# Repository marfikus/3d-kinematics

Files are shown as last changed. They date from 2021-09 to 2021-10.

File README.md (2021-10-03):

# 3d-kinematics

Прошивка для самодельной 3х-осевой кинематики, собранной из имеющегося в наличии хлама. Экспериментальный вариант. Никаких серьёзных подшипников (что конечно сказывается на точности). По оси Z(вертикаль) зубчатые передачи (лоток CD/DVD привода), по осям X,Y фрикционные передачи. Тестил пока только с карандашом, рисуя разные фигуры. Кстати, неплохое учебное пособие для изучения геометрии, тригонометрии, механики, ну и конечно программирования =).

Два режима: работа и калибровка. В режиме калибровки можно отдельно двигать каждую ось и задавать ноль. В рабочем режиме выполняется движение по массиву точек. Можно остановить работу, увести оси на ноль, поднять/опустить голову с карандашом.

В зависимости от настроек, что задаются константами в начале файла прошивки, можно активировать режим движения к каждой точке по нажатию кнопки. Также можно активировать коррекцию погрешности механики (внесение поправки в координаты). Есть ещё разные настройки, которые я постарался снабдить комментариями.

Компоненты:  
Мозги: Arduino UNO  
Шаговые движки: 28BYJ-48 на 5V с драйверами ULN2003. По одному движку на оси X, Y и два на ось Z (включены параллельно).  
Ещё 3 кнопки и два тумблера. Один двухпозиционный для переключения режимов работы, другой трёхпозиционный для переключения осей в режиме калибровки. Ну и несколько резисторов, провода и достаточное желание всё это собрать воедино.

Электрическая схема:
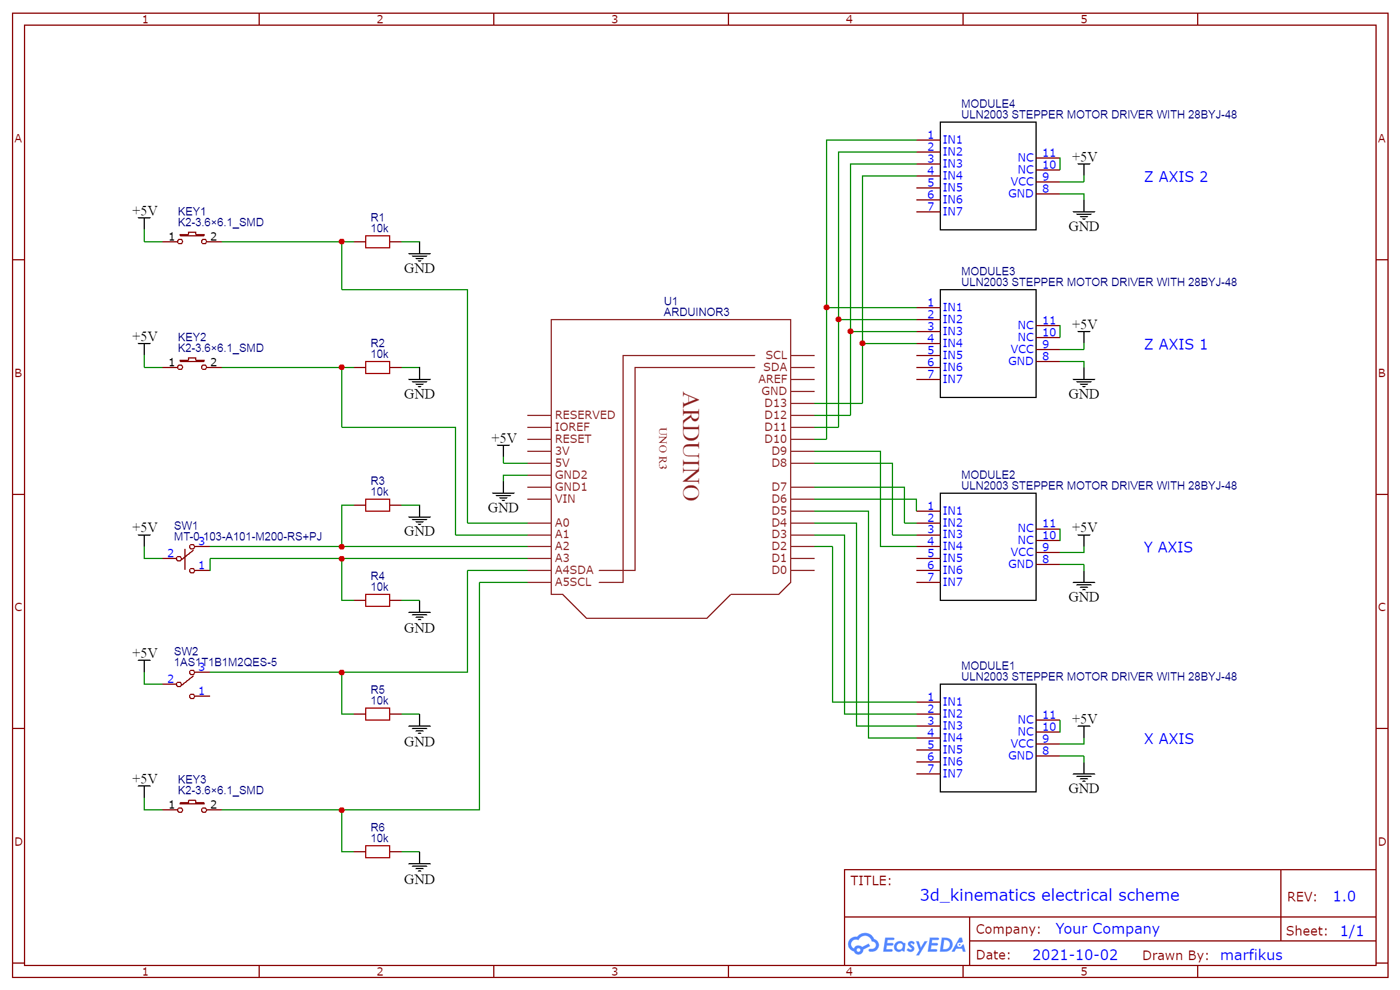
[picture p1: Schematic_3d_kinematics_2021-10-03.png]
Schematic_3d_kinematics_2021-10-03


Статья про то, как всё это создавалось:  
[ВКонтакте](https://vk.com/@marfikus_notes-simple-diy-3d-kinematics)  
[LiveJournal](https://marfikus.livejournal.com/19188.html)

[Краткий видео-обзор и демонстрация работы](https://youtu.be/FhWhIIZW5xA)

В каталоге [3d_models](https://github.com/marfikus/3d-kinematics/tree/master/3d_models) находятся 3d-модели деталей и сборок. Собственно, сначала смоделировал основные узлы (увлекательное занятие), потом начал делать. В реальности всё выглядит практически также.  
Вот модель общей сборки на данный момент (ещё не завершена):
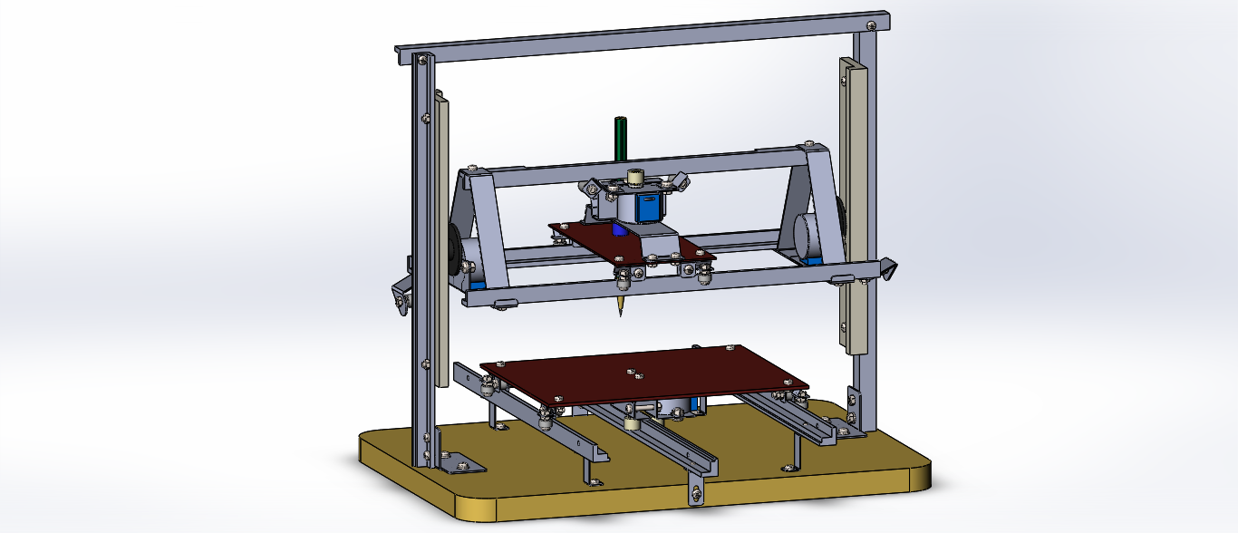
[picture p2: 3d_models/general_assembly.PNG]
general_assembly


Моделировал в Solid Works 2016. Для просмотра можно установить универсальный вьювер eDrawings. Вот [ссылка на его загрузку](https://www.edrawingsviewer.com/download-edrawings) или можно поискать по запросу "solidworks viewer".

Заметил, что включенный Serial мешает рисовать окружности с большим количеством точек. В какой-то момент сбивается с координат и просто ведёт линию по одной из осей. Даже если нет ни одного принта. Если в массиве, например, 60 точек, то отрабатывает нормально, а с 90 уже сбивается.  
По идее надо бы вообще не создавать массив, а отдавать конкретную точку прямо в процессе работы. Так будет гораздо экономичнее по памяти и этот баг наверное устранится. Возможно в будущем так и сделаю.  
При выключенном Serial всё нормально.

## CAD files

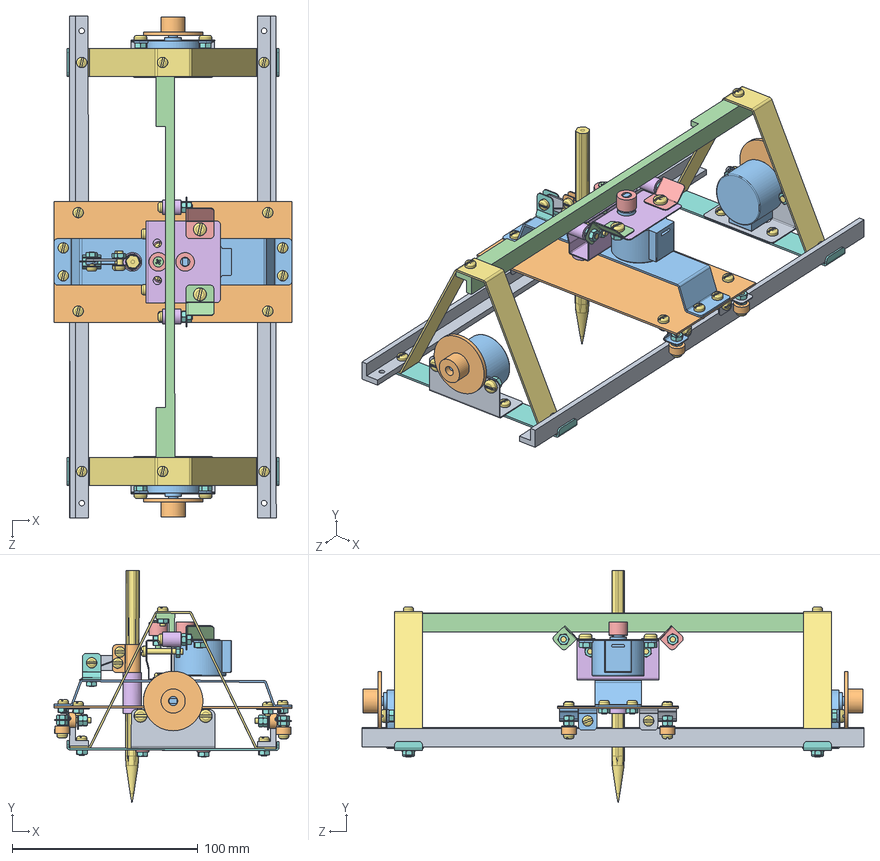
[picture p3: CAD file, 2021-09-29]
3d_models/z_axis_assembly_version_3_final.SLDASM
128.0 x 125.0 x 270.0 mm
corner_rail_2 x 2
table_2
stepper x 3
corner_rail_3
rubberized_roller x 2
table_2_stepper_holder
z_axis_rails_holder_1_1 x 2
z_axis_rails_holder_1_2 x 2
z_axis_stepper_holder x 2
gear_imitation x 2
table_2_stepper_support_2
table_2_stepper_rail_support_left
table_2_stepper_rail_support_right
long_roller x 2
pan slot head_am x 42
hex nut style 1_am x 54
table_support_1 x 2
short_roller x 8
table_support_2 x 2
flat head screw_am
flat washer narrow_am x 6
pencil_tube
pencil
pencil_bracing_1_1
pencil_bracing_1_2
pencil_bracing_1_3
pencil_bracing_spring

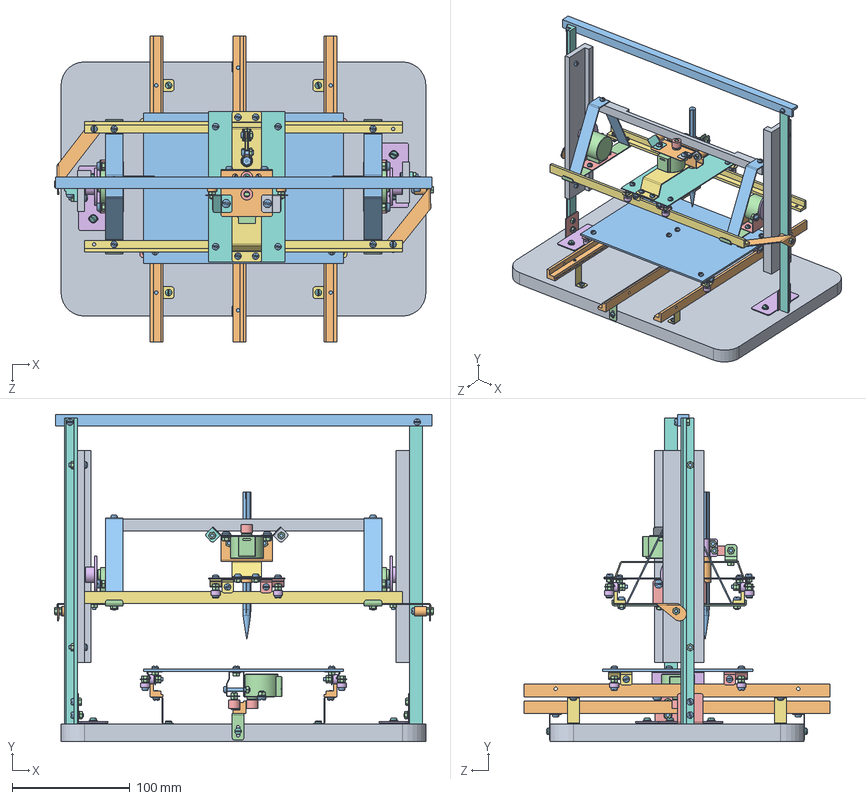
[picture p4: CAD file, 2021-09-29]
3d_models/general_assembly.SLDASM
322.0 x 278.0 x 260.0 mm
base
corner_rail_1 x 3
table_1
stepper x 4
rubberized_roller x 4
table_1_stepper_holder
corner_rail_2 x 2
table_2
corner_rail_3
table_2_stepper_holder
z_axis_rails_holder_1_1 x 2
z_axis_rails_holder_1_2 x 2
z_axis_stepper_holder x 2
gear_imitation x 2
table_2_stepper_support_2
table_2_stepper_rail_support_left
table_2_stepper_rail_support_right
long_roller x 4
pan slot head_am x 80
hex nut style 1_am x 98
table_support_1 x 4
short_roller x 16
table_support_2 x 4
flat head screw_am x 2
flat washer narrow_am x 14
pencil_tube
pencil
pencil_bracing_1_1
pencil_bracing_1_2
pencil_bracing_1_3
pencil_bracing_spring
z_axis_rack x 2
toothed_rail_imitation x 2
z_axis_side_support x 2
z_axis_upper_corner
table_1_stepper_rail_support x 2
z_axis_rack_bracing_1_1 x 2
z_axis_rack_bracing_1_2 x 2
table_1_rail_support x 4
pan head tapping screw_am x 10

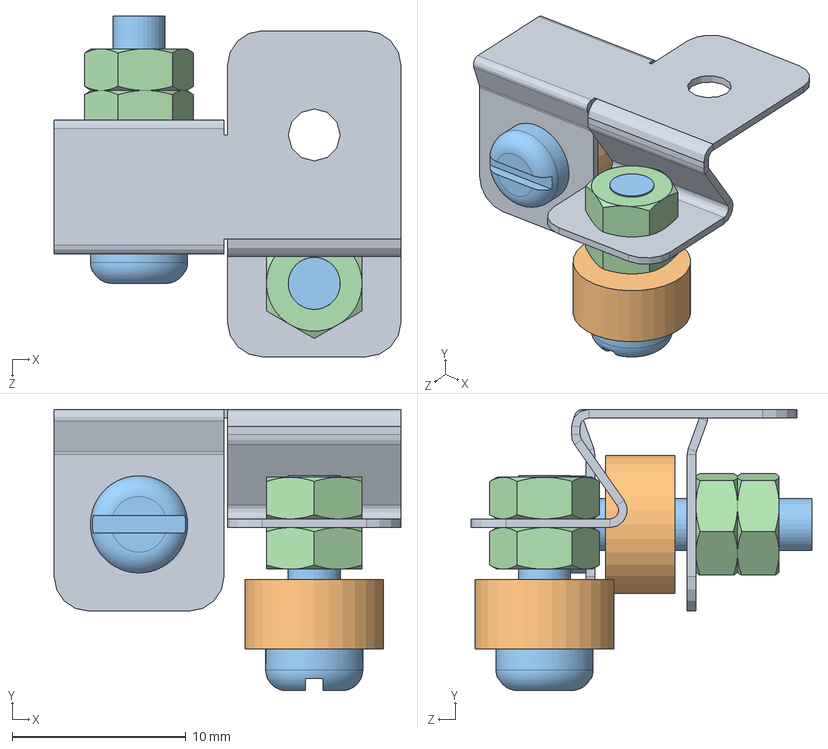
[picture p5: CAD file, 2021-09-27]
3d_models/table_support_left_assembly.SLDASM
20.0 x 16.2 x 19.6 mm
table_support_1
short_roller x 2
pan slot head_am x 2
hex nut style 1_am x 4

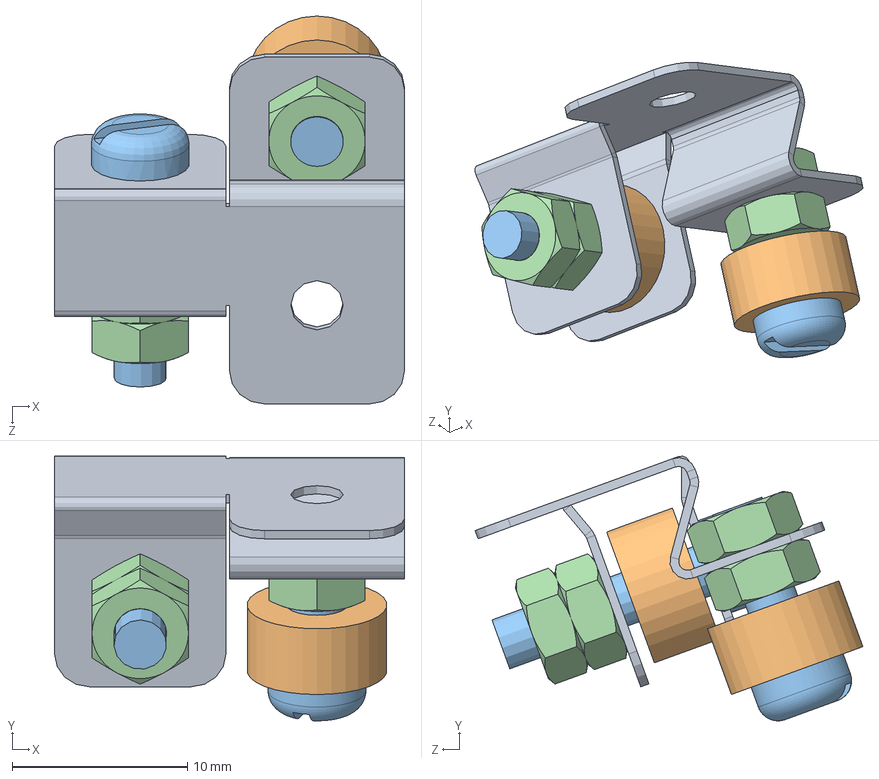
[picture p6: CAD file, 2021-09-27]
3d_models/table_support_right_assembly.SLDASM
20.0 x 15.1 x 22.2 mm
table_support_2
short_roller x 2
pan slot head_am x 2
hex nut style 1_am x 4

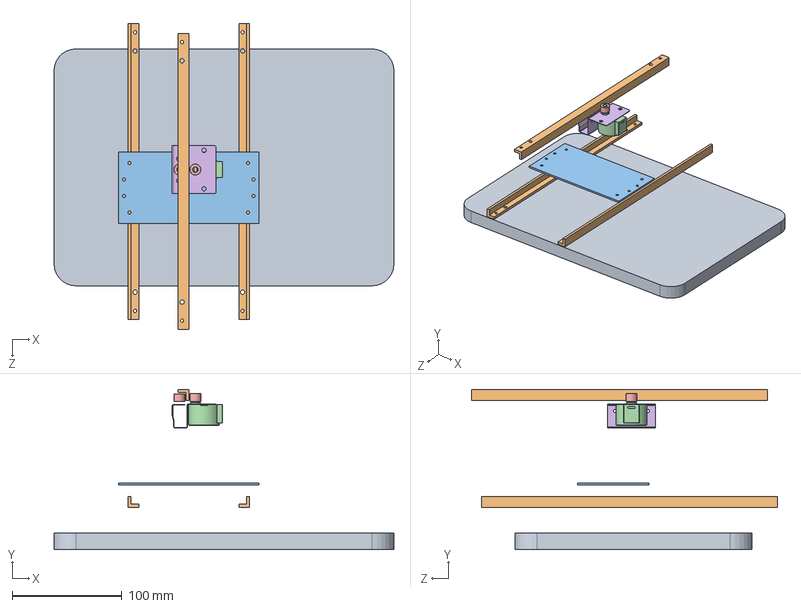
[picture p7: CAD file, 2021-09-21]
3d_models/z_axis_assembly_version_2.SLDASM
310.0 x 146.2 x 279.0 mm
corner_rail_2 x 3
table_2
stepper
rubberized_roller x 2
table_2_stepper_holder

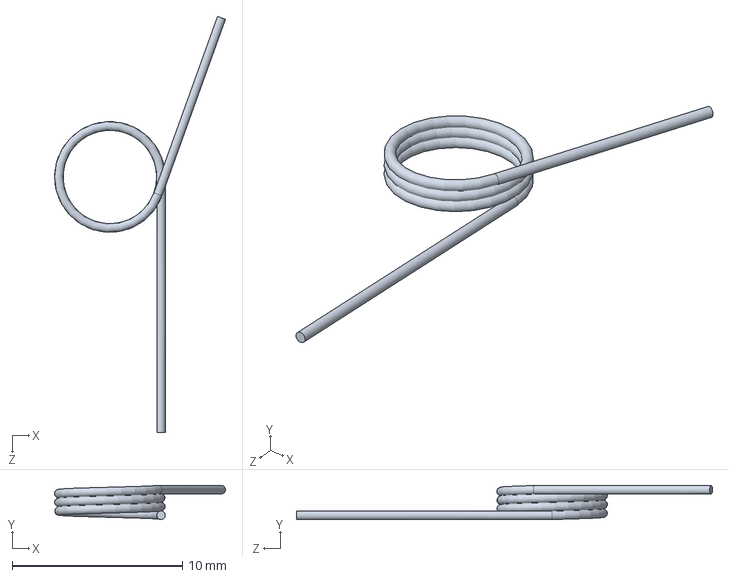
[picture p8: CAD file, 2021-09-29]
3d_models/parts/pencil_bracing_spring.SLDPRT
10.0 x 2.00 x 24.4 mm

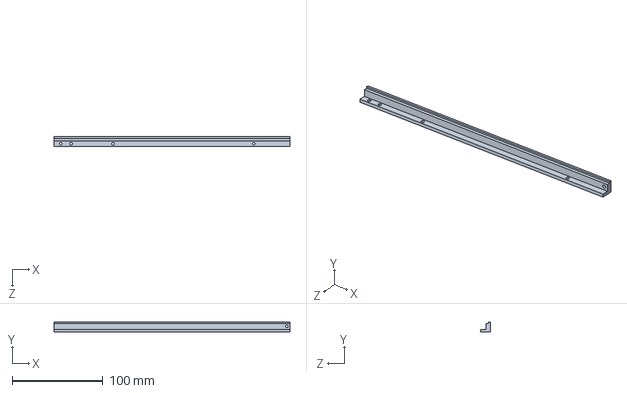
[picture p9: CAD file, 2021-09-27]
3d_models/parts/z_axis_rack.SLDPRT
260.0 x 11.0 x 11.0 mm

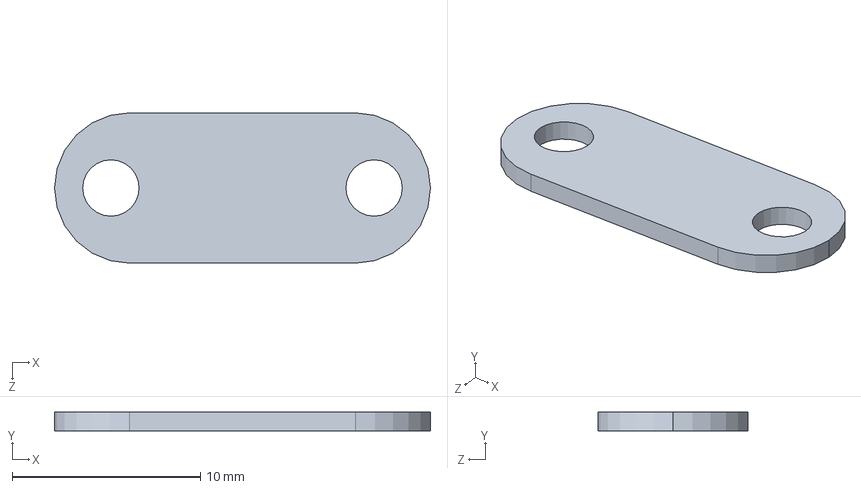
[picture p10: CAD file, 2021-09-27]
3d_models/parts/pencil_bracing_1_2.SLDPRT
20.0 x 1.00 x 8.00 mm

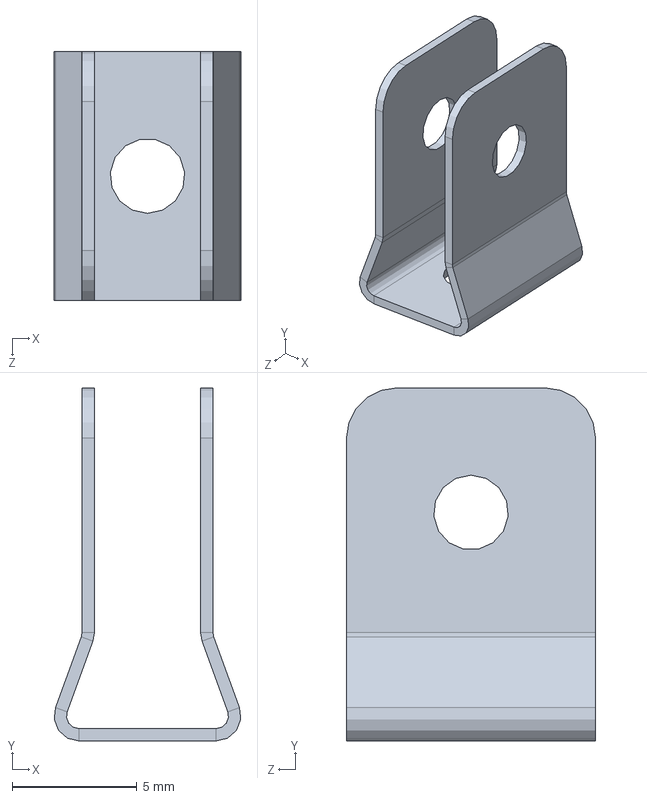
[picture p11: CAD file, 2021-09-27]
3d_models/parts/pencil_bracing_1_1.SLDPRT
7.49 x 14.2 x 10.0 mm

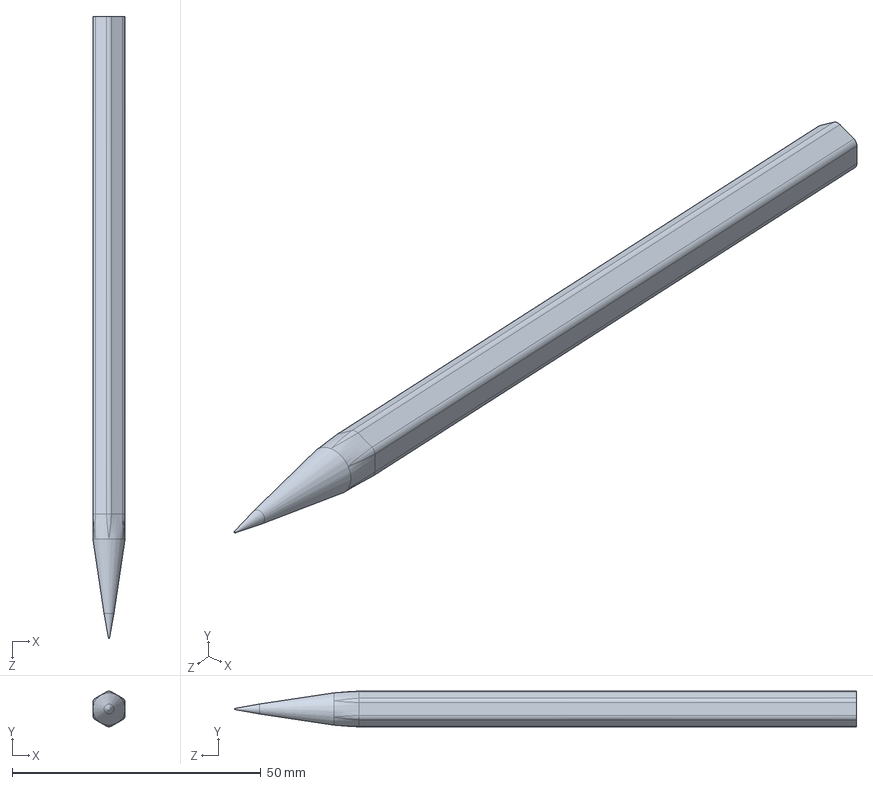
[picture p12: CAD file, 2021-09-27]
3d_models/parts/pencil.SLDPRT
6.50 x 7.20 x 125.0 mm

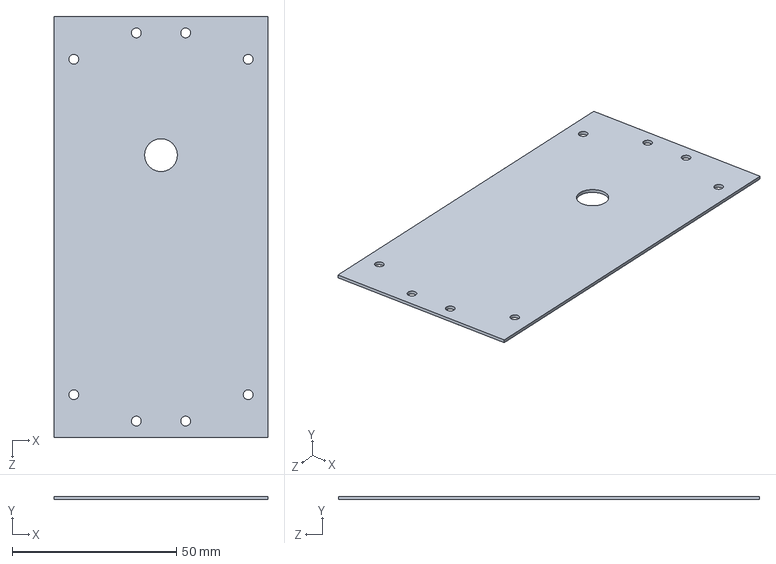
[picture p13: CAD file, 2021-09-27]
3d_models/parts/table_2.SLDPRT
65.0 x 1.00 x 128.0 mm

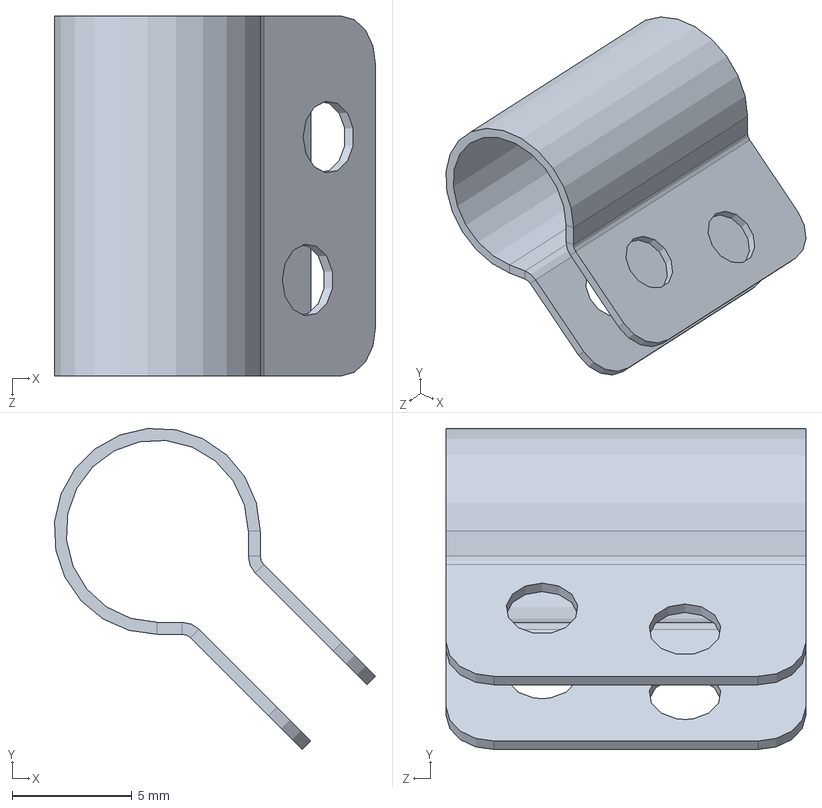
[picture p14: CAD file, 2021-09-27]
3d_models/parts/pencil_bracing_1_3.SLDPRT
13.4 x 13.4 x 15.0 mm

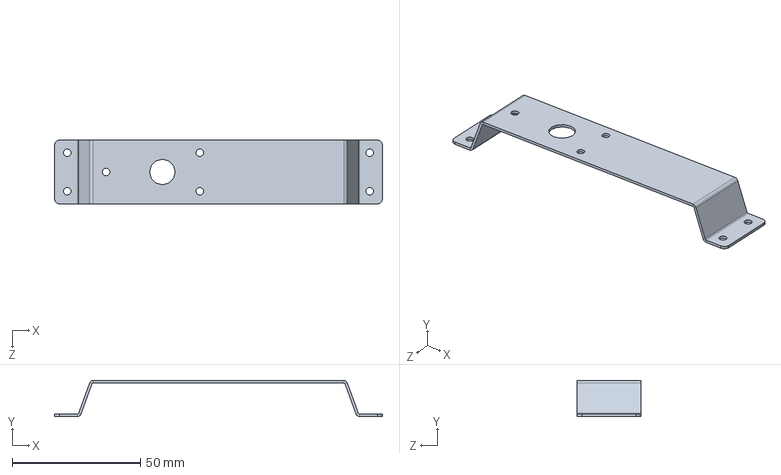
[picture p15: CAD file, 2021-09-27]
3d_models/parts/table_2_stepper_support_2.SLDPRT
128.0 x 14.1 x 25.0 mm

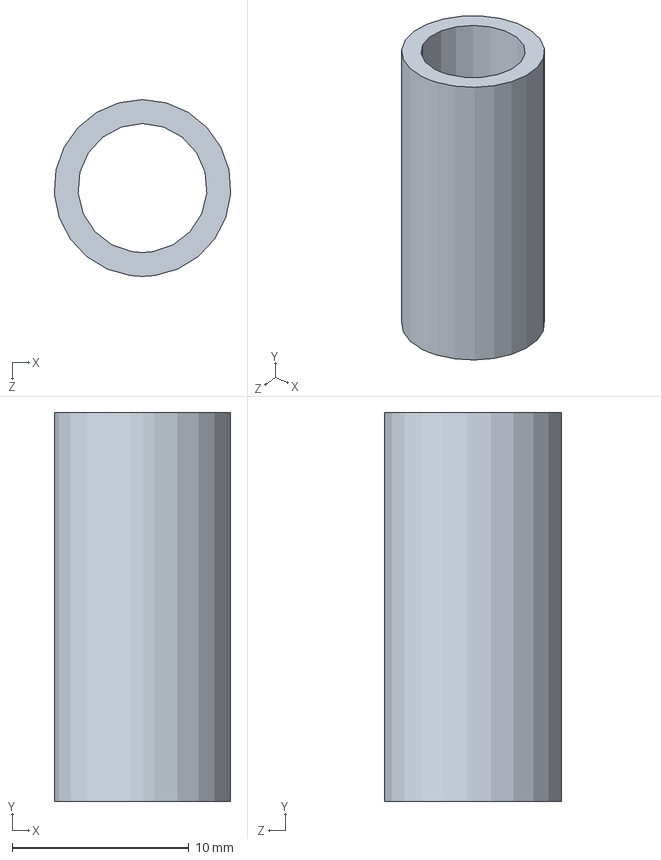
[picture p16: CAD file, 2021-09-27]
3d_models/parts/pencil_tube.SLDPRT
9.98 x 22.0 x 10.0 mm

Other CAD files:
3d_models/parts/corner_rail_1.SLDPRT
3d_models/parts/table_2_stepper_holder.SLDPRT
3d_models/parts/z_axis_side_support.SLDPRT
3d_models/parts/table_2_stepper_rail_support_right.SLDPRT
3d_models/parts/base.SLDPRT
3d_models/parts/corner_rail_2.SLDPRT
3d_models/parts/corner_rail_3.SLDPRT
3d_models/parts/gear_imitation.SLDPRT
3d_models/parts/long_roller.SLDPRT
3d_models/parts/rubberized_roller.SLDPRT
3d_models/parts/short_roller.SLDPRT
3d_models/parts/stepper.SLDPRT
3d_models/parts/table_1.SLDPRT
3d_models/parts/table_1_rail_support.SLDPRT
3d_models/parts/table_1_stepper_holder.SLDPRT
3d_models/parts/table_1_stepper_rail_support.SLDPRT
3d_models/parts/table_2_stepper_rail_support_left.SLDPRT
3d_models/parts/table_2_stepper_support.SLDPRT
3d_models/parts/table_support_1.SLDPRT
3d_models/parts/table_support_2.SLDPRT
3d_models/parts/toothed_rail_imitation.SLDPRT
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

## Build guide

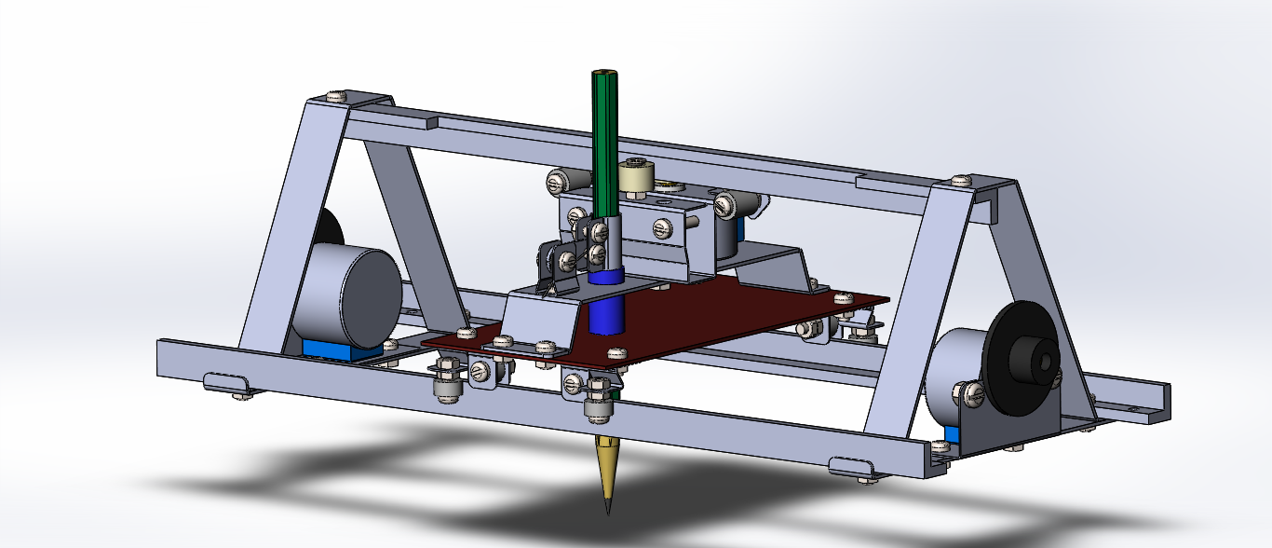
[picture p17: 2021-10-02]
3d_models/z_axis_assembly_version_3_final.PNG

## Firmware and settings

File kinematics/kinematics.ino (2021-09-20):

#include <GyverStepper.h>

GStepper<STEPPER4WIRE> stepperX(2048, 5, 3, 4, 2);
/* подключение к драйверу:
in 1 - 2 
in 2 - 3
in 3 - 4
in 4 - 5
*/

GStepper<STEPPER4WIRE> stepperY(2048, 9, 7, 8, 6);
/* подключение к драйверу:
in 1 - 6 
in 2 - 7
in 3 - 8
in 4 - 9
*/

GStepper<STEPPER4WIRE> stepperZ(2048, 13, 11, 12, 10);
/* подключение к драйверу (тут на два драйвера параллельно):
in 1 - 10 
in 2 - 11
in 3 - 12
in 4 - 13
*/

// BT - кнопка, SW - тумблер
const byte BT_1 = A0; // кнопка без фиксации
const byte BT_2 = A1; // кнопка без фиксации
// трёхпозиционный тумблер для переключения осей в режиме калибровки:
const byte SW_1_1 = A2;
const byte SW_1_2 = A3;
// двухпозиционный тумблер для переключения режимов (калибровка/работа):
const byte SW_2 = A4; 
const byte BT_3 = A5; // кнопка без фиксации

// активация serial:
// Заметил, что включенный serial мешает рисовать окружности с большим 
// количеством точек(сбивается с координат).
const bool SERIAL_ENABLED = false;
const long SERIAL_SPEED = 9600;

// максимальные скорости движения осей:
// (реальные скорости будут вычисляться в работе для равномерного движения)
// для одного движка, больше 540 клинит иногда, для двух в параллель больше 450
const float MAX_SPEED_X = 400;
const float MAX_SPEED_Y = 400;
const float MAX_SPEED_Z = 300;

// активация коррекции погрешности механики (внесение поправки в координаты)
const bool CORRECTION_ENABLED = true;
// величины корректировок
const int X_CORRECTION = 50;
const int Y_CORRECTION = 0;
// величина начального сдвига для определения последних направлений
const int SHIFT = 500;

// верхняя и нижняя позиции головы (ось z)
const int UP_HEAD_POSITION = -200;
const int DOWN_HEAD_POSITION = 0;

// активация режима движения к каждой точке массива по нажатию кнопки
const bool NEXT_POINT_FROM_BUTTON = false;


// массив точек:
// первый элемент - положение головки(0 - поднята, 1 - опущена)
// второй элемент - координата х
// третий элемент - координата у

// прямоугольник:
int POINTS[][3] = {
    {0, 3000, 1000},
    {1, 3000, 2000},
    {1, 4000, 2000},
    {1, 4000, 1000},
    {1, 3000, 1000}
};

//прямоугольный треугольник:
/*int POINTS[][3] = {
    {0, 1700, 600},
    {1, 1700, 3600},
    {1, 4700, 600},
    {1, 1700, 600},
};*/

// равнобедренный треугольник:
/*int POINTS[][3] = {
    {0, 1000, 1500},
    {1, 2500, 500},
    {1, 2500, 2500},
    {1, 1000, 1500},
};*/

// прямоугольный треугольник 2:
/*int POINTS[][3] = {
    {0, 500, 1000},
    {1, 2000, 1000},
    {1, 2000, 0},
    {1, 500, 1000},
};*/

// восьмиугольник:
/*int POINTS[][3] = {
    {0, 2000, 1000},
    {1, 3000, 1000},
    {1, 4000, 2000},
    {1, 4000, 3000},
    {1, 3000, 4000},
    {1, 2000, 4000},
    {1, 1000, 3000},
    {1, 1000, 2000},
    {1, 2000, 1000},
};*/

// подобие розы ветров:
/*int POINTS[][3] = {
    {0, 0, 2500},
    {1, 1500, 3000},
    {1, 1000, 4000},
    {1, 2000, 3500},
    {1, 2500, 5000},
    {1, 3000, 3500},
    {1, 4000, 4000},
    {1, 3500, 3000},
    {1, 5000, 2500},
    {1, 3500, 2000},
    {1, 4000, 1000},
    {1, 3000, 1500},
    {1, 2500, 0},
    {1, 2000, 1500},
    {1, 1000, 1000},
    {1, 1500, 2000},
    {1, 0, 2500},
};*/

// вычисление количества элементов в массиве:
// (только если массив заполняется вручную (варианты выше),
// иначе (для генерируемого массива) размер задается ниже!)
const int POINTS_SIZE = sizeof(POINTS) / sizeof(POINTS[0]);


// окружность или если использовать generateCirclePointsArray2,
// то можно получить многоугольник с заданным числом вершин
// (массив заполняется при запуске в generateCirclePointsArray
// или в generateCirclePointsArray2 (раскомментировать нужное в setup)):
// центр и радиус:
const int X0 = 3000;
const int Y0 = 1000;
const int RADIUS = 1000;
// шаг координат (для generateCirclePointsArray):
const int STEP = 50;
// количество вершин (для generateCirclePointsArray2):
// (при VERTEX_NUMBER >= 90 и включенном Serial сбивается с координат)
// const int VERTEX_NUMBER = 3; // получим равносторонний треугольник
const int VERTEX_NUMBER = 60; // получим вполне ровную окружность
// размер массива: 
// для generateCirclePointsArray:
// const int POINTS_SIZE = ((RADIUS / STEP) * 4) + 1;
// для generateCirclePointsArray2:
// const int POINTS_SIZE = VERTEX_NUMBER + 1;
// создание массива для окружности:
// int POINTS[POINTS_SIZE][3];


// звезда или другая подобная фигура с двумя радиусами (меньший и больший)
// (массив заполняется при запуске в generateStarPointsArray
// (раскомментировать нужное в setup)):
// количество лучей:
const int RAYS_NUMBER = 5;
// центр:
// const int X0 = 1000;
// const int Y0 = 1000;
// больший радиус:
const int R1 = 1000;
// меньший радиус:
const int R2 = 400;
// размер массива и его создание:
// const int POINTS_SIZE = RAYS_NUMBER * 2 + 1;
// int POINTS[POINTS_SIZE][3];


enum {
    X,
    Y,
    Z
} currentAxis;

enum {
    CALIBRATION,
    WORK
} currentMode;

enum {
    AWAIT_COMMAND,
    GOING_TO_ZERO,
    GOING_BY_POINTS,
    HEAD_MOVING,
    LAST_DIRECTIONS_DETECTING
} workState;

enum {
    UP,
    DOWN
} headPosition;

enum Directions {
    RIGHT,
    LEFT
};
Directions xLastDirection;
Directions yLastDirection;
Directions xNeedDirection;
Directions yNeedDirection;

enum {
    START,
    ZERO_REACHED,
    SHIFT_REACHED
} detectLastDirectionsState;

bool lastDirectionsDetected = false;
bool correctedValues = false;
int correctedX = 0;
int correctedY = 0;
int xCorrection = 0;
int yCorrection = 0;

bool calibrationModeActive = false;
bool workModeActive = false;
bool awaitButton = true;
int currentPoint = 0;
bool steppersSpeedCorrected = false;

struct SquareEquationCoefficients {
    long a;
    long b;
    long c;
};

struct SquareEquationResult {
    byte statusCode;
    long r1;
    long r2;
};

SquareEquationCoefficients getSquareEquationCoefficients(long x0, long y0, long x, long radius) {
    /*
    Получает коэффициенты квадратного уравнения 
    из имеющихся данных о окружности
    */

    long a = 1;
    long b = 2 * (-y0);
    long c = sq(-y0) - (sq(radius) - sq(x - x0));

    return (SquareEquationCoefficients) {a, b, c};   
}

SquareEquationResult solveSquareEquation(long a, long b, long c) {
    /*
    Решает квадратное уравнение
    */

    byte statusCode = 0;
    long r1 = 0;
    long r2 = 0;
    long d = (b * b) - 4 * a * c;

    if (d > 0) {
        // два корня
        statusCode = 2;
        long sqrtD = sqrt(d);
        r1 = round((-b + sqrtD) / 2 * a);
        r2 = round((-b - sqrtD) / 2 * a);
    } else if (d == 0) {
        // один корень
        statusCode = 1;
        r1 = round(-b / 2 * a);
    } else {
        // нет корней
    }

    return (SquareEquationResult) {statusCode, r1, r2};
}

void generateCirclePointsArray() {
    /*
    Заполняет массив точек, посредством решения 
    квадратных уравнений для точек одной четверти, 
    а потом симметрично заполняет остальные.
    Не очень оптимальный вариант, да и результат получается
    не совсем равномерный, видны небольшие углы.
    Сделал больше из интереса, а для реальных задач лучше 
    использовать generateCirclePointsArray2, расположенный ниже.
    */

    int xMin = X0 - RADIUS;
    int xMax = X0 + RADIUS;
    int yMin = Y0 - RADIUS;
    int yMax = Y0 + RADIUS;

    int pos1 = 0;
    int pos4 = (POINTS_SIZE - 1) - pos1;
    int pos3 = (POINTS_SIZE - 1) / 2;
    int pos2 = (POINTS_SIZE - 1) - pos3;

    for (int x = xMin, x2 = xMax; x < X0; x += STEP, x2 -= STEP) {
        POINTS[pos1][0] = 1;
        POINTS[pos1][1] = x;

        POINTS[pos3][0] = 1;
        POINTS[pos3][1] = x2;

        SquareEquationCoefficients coefs = getSquareEquationCoefficients(X0, Y0, x, RADIUS);
        SquareEquationResult result = solveSquareEquation(coefs.a, coefs.b, coefs.c);

        // заполнение всех четвертей за один проход
        // если 2 корня, то меньший ставим в текущую точку, а больший симметрично в верхнюю четверть,
        // ну и другие тоже симметрично (на графике сразу понятно)
        if (result.statusCode == 2) {
            POINTS[pos4][0] = 1;
            POINTS[pos4][1] = x;

            POINTS[pos2][0] = 1;
            POINTS[pos2][1] = x2;

            if (result.r1 < result.r2) {
                POINTS[pos1][2] = result.r1;
                POINTS[pos4][2] = result.r2;

                POINTS[pos2][2] = result.r1;
                POINTS[pos3][2] = result.r2;
            } else {
                POINTS[pos1][2] = result.r2;
                POINTS[pos4][2] = result.r1;

                POINTS[pos2][2] = result.r2;
                POINTS[pos3][2] = result.r1;
            }
        // если 1 корень, то ставим его в текущую точку
        } else if (result.statusCode == 1) {
            POINTS[pos1][2] = result.r1;

            POINTS[pos3][2] = result.r1;
        // если нет корней (что маловероятно), то
        } else if (result.statusCode == 0) {
            // если не первая точка, то ставим в неё значение из предыдущей, иначе Y0
            if (pos1 != 0) {
                POINTS[pos1][2] = POINTS[pos1 - 1][2];
                POINTS[pos2][2] = POINTS[pos2 - 1][2];
                POINTS[pos3][2] = POINTS[pos3 - 1][2];
                POINTS[pos4][2] = POINTS[pos4 - 1][2];
            } else {
                POINTS[pos1][2] = Y0;
                POINTS[pos2][2] = Y0;
                POINTS[pos3][2] = Y0;
                POINTS[pos4][2] = Y0;
            }
        }
        
        pos1++;
        pos4 = (POINTS_SIZE - 1) - pos1;
        pos3++;
        pos2 = (POINTS_SIZE - 1) - pos3;
    }

    // заполнение оставшихся крайних точек
    // (можно наверное и их в цикле заполнить, но пока не сообразил)
    POINTS[pos1][0] = 1;
    POINTS[pos1][1] = X0;
    POINTS[pos1][2] = yMin;

    POINTS[pos3][0] = 1;
    POINTS[pos3][1] = X0;
    POINTS[pos3][2] = yMax;

    // указываем, чтобы к первой точке двигался с поднятой головой
    POINTS[0][0] = 0;

    // заполняем последнюю точку, чтобы замкнуть круг
    POINTS[POINTS_SIZE - 1][0] = 1;
    POINTS[POINTS_SIZE - 1][1] = POINTS[0][1];
    POINTS[POINTS_SIZE - 1][2] = POINTS[0][2];
}

void generateCirclePointsArray2() {
    /*
    В общем делает то же самое, что и предыдущая функция, 
    но гораздо короче, точнее и наверное оптимальнее.
    Кроме того, играясь с константами в начале файла, можно получить
    разные многоугольники.
    */

    int angle = 0;
    int angleStep = round(360 / (POINTS_SIZE - 1));

    for (int i = 0; i < POINTS_SIZE; i++) {

        POINTS[i][0] = 1;
        POINTS[i][1] = RADIUS * cos(radians(angle)) + X0;
        POINTS[i][2] = RADIUS * sin(radians(angle)) + Y0;

        angle += angleStep;
    }

    POINTS[0][0] = 0;
}

void generateStarPointsArray() {
    /*
    Генерирует точки звезды с заданным количеством лучей.
    Больший радиус определяет крайнюю точку луча, 
    меньший - основание. 
    Играясь с константами в начале файла, можно получить разные фигуры.
    */

    int angle1 = 0;
    int angle2 = round(360 / (POINTS_SIZE - 1));
    int angleStep = angle2 * 2;

    for (int i = 0, j = 1; j < POINTS_SIZE; i += 2, j += 2) {

        POINTS[i][0] = 1;
        POINTS[i][1] = R1 * cos(radians(angle1)) + X0;
        POINTS[i][2] = R1 * sin(radians(angle1)) + Y0;

        POINTS[j][0] = 1;
        POINTS[j][1] = R2 * cos(radians(angle2)) + X0;
        POINTS[j][2] = R2 * sin(radians(angle2)) + Y0;

        angle1 += angleStep;
        angle2 += angleStep;
    }

    POINTS[POINTS_SIZE - 1][0] = 1;
    POINTS[POINTS_SIZE - 1][1] = POINTS[0][1];
    POINTS[POINTS_SIZE - 1][2] = POINTS[0][2];

    POINTS[0][0] = 0;
}

void detectCurrentMode() {
    /*
    Определяет текущий режим работы по положению тумблера
    */

    if (digitalRead(SW_2) == HIGH) {
        currentMode = CALIBRATION;
    } else {
        currentMode = WORK;
    }
}

void detectCurrentAxis() {
    /*
    Определяет текущую ось по положению тумблера (в режиме калибровки)
    */

    if (digitalRead(SW_1_1) == HIGH) {
        currentAxis = X;
    } else if (digitalRead(SW_1_2) == HIGH) {
        currentAxis = Y;
    } else {
        currentAxis = Z;
    }
}

void forward() {
    /*
    Движение вперед для текущей оси (в режиме калибровки)
    */

    if (currentAxis == X) {
        if (!stepperX.tick()) {
            stepperX.setSpeed(MAX_SPEED_X);
        }
    } else if (currentAxis == Y) {
        if (!stepperY.tick()) {
            stepperY.setSpeed(MAX_SPEED_Y);
        }
    } else if (currentAxis == Z) {
        if (!stepperZ.tick()) {
            stepperZ.setSpeed(MAX_SPEED_Z);
        }
    }
}

void back() {
    /*
    Движение назад для текущей оси (в режиме калибровки)
    */

    if (currentAxis == X) {
        if (!stepperX.tick()) {
            stepperX.setSpeed(-MAX_SPEED_X);
        }
    } else if (currentAxis == Y) {
        if (!stepperY.tick()) {
            stepperY.setSpeed(-MAX_SPEED_Y);
        }
    } else if (currentAxis == Z) {
        if (!stepperZ.tick()) {
            stepperZ.setSpeed(-MAX_SPEED_Z);
        }
    }
}

void stop() {
    /*
    Остановка текущей оси (в режиме калибровки)
    или остановка всех осей (в режиме работы)
    */

    if (currentMode == CALIBRATION) {
        if (currentAxis == X) {
            stepperX.brake();
        } else if (currentAxis == Y) {
            stepperY.brake();
        } else if (currentAxis == Z) {
            stepperZ.brake();
        }
    } else if (currentMode == WORK) {
        stepperX.brake();
        stepperY.brake();
        stepperZ.brake();
    }
}

void setZero() {
    /*
    Установка нуля для текущей оси (в режиме калибровки)
    */

    if (currentAxis == X) {
        stepperX.reset();
    } else if (currentAxis == Y) {
        stepperY.reset();
    } else if (currentAxis == Z) {
        stepperZ.reset();
    }
}

bool goToZero(bool moveHeadDown) {
    /*
    Движение осей к текущим нулям (в режиме работы)

    Флаг moveHeadDown позволяет при необходимости 
    не опускать голову в конце процедуры.

    Если одновременно включить 4 движка, то питание проседает,
    поэтому сначала выгоняю в 0 оси X, Y, а потом Z.
    Да и поскольку сейчас 0 у Z это нижняя точка, то надо сначала увести стол.
    */

    bool xyZeroReached = false;
    bool zeroReached = false;

    // если голова поднята, то выгоняем оси, иначе сначала поднимаем голову
    if (headPosition == UP) {
        xyZeroReached = goToPoint(0, 0, true);
    } else {
        moveHead(0);
    }

    if (xyZeroReached) {
        // если нужно опускаем голову
        if (moveHeadDown) {
            bool headMoved = moveHead(1);
            if (headMoved) {
                zeroReached = true;
            }
        } else {
            zeroReached = true;
        }
    }

    return zeroReached;
}

// перегрузка функции, чтобы можно было вызвать без параметров
bool goToZero() {
    return goToZero(true);
}

bool goToPoint(int x, int y, bool resetSpeed) {
    /*
    Движение к указанной координате (в режиме работы)

    Флаг resetSpeed передаётся в correctSteppersSpeed,
    чтобы при необходимости можно было сбросить скорости движков.
    */

    bool xReached = false;
    bool yReached = false;
    bool pointReached = false;

    if (!steppersSpeedCorrected) {
        correctSteppersSpeed(x, y, resetSpeed);
    }

    if (stepperX.getCurrent() != x) {
        if (!stepperX.tick()) {
            stepperX.setTarget(x);
        }
    } else {
        stepperX.brake();
        xReached = true;
    }

    if (stepperY.getCurrent() != y) {
        if (!stepperY.tick()) {
            stepperY.setTarget(y);
        }
    } else {
        stepperY.brake();
        yReached = true;
    }

    if (xReached && yReached) {
        pointReached = true;
        steppersSpeedCorrected = false;
    }

    return pointReached;
}

bool goToPoint(int x, int y) {
    return goToPoint(x, y, false);
}
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
void loop()	{
    detectCurrentMode();

    if (currentMode == CALIBRATION) {
        setupCalibrationMode();
        detectCurrentAxis();

    	if (digitalRead(BT_1) == HIGH) {
            forward();
    	} else if (digitalRead(BT_2) == HIGH) {
            back();
    	} else {
            stop();
    	}

        if (digitalRead(BT_3) == HIGH) {
            setZero();
        }

    } else if (currentMode == WORK) {
        setupWorkMode();

        // кнопка 2
        if (digitalRead(BT_2) == HIGH) {
            // в режиме простоя - поднять/опустить голову
            if (workState == AWAIT_COMMAND) {
                // защита от дребезга контактов
                delay(10);
                if (digitalRead(BT_2) == HIGH) {
                    // ждем когда кнопка будет отжата
                    while (true) {
                        if (digitalRead(BT_2) == LOW) {
                            delay(10);
                            if (digitalRead(BT_2) == LOW) {
                                workState = HEAD_MOVING;
                                break;
                            }
                        }
                    }
                }
            // в остальных режимах - полная остановка
            } else {
                stop();
                currentPoint = 0;
                correctedValues = false;
                xCorrection = 0;
                yCorrection = 0;
                awaitButton = true;
                lastDirectionsDetected = false;
                steppersSpeedCorrected = false;
                workState = AWAIT_COMMAND;
                delay(2000); // пауза для того, чтобы кнопка сразу не сработала повторно                
            }
        // кнопка 1 - пуск движения по массиву точек
        } else if (digitalRead(BT_1) == HIGH) {
            if (awaitButton) {
                delay(10);
                if (digitalRead(BT_1) == HIGH) {
                    while (true) {
                        if (digitalRead(BT_1) == LOW) {
                            delay(10);
                            if (digitalRead(BT_1) == LOW) {
                                if (CORRECTION_ENABLED) {
                                    if (!lastDirectionsDetected) {
                                        workState = LAST_DIRECTIONS_DETECTING;
                                        detectLastDirectionsState = START;
                                    } else {
                                        workState = GOING_BY_POINTS;
                                    }
                                } else {
                                    workState = GOING_BY_POINTS;
                                }
                                awaitButton = false;
                                break;
                            }
                        }
                    }
                }
            }
        // кнопка 3
        } else if (digitalRead(BT_3) == HIGH) {
            // в режиме простоя - отвод осей в 0
            if (workState == AWAIT_COMMAND) {
                workState = GOING_TO_ZERO;
            }
        }

        if (workState == GOING_TO_ZERO) {
            bool zeroReached = goToZero();
            
            if (zeroReached) {
                workState = AWAIT_COMMAND;
            }

        } else if (workState == LAST_DIRECTIONS_DETECTING) {
            detectLastDirections();
            if (lastDirectionsDetected) {
                workState = GOING_BY_POINTS;
                correctedValues = false;
                xCorrection = 0;
                yCorrection = 0;
            }

        } else if (workState == GOING_BY_POINTS) {
            // если не ждем нажатия кнопки, то работаем
            if (!awaitButton) {
                int z = POINTS[currentPoint][0];
                bool headMoved = moveHead(z);

                if (headMoved) {
                    int x = POINTS[currentPoint][1];
                    int y = POINTS[currentPoint][2];

                    if (CORRECTION_ENABLED) {
                        if (!correctedValues) {
                            correctedX = correctValue('x', x);
                            correctedY = correctValue('y', y);
                            correctedValues = true;
                        }
                        x = correctedX;
                        y = correctedY;
                    }

                    bool pointReached = goToPoint(x, y);
                    if (pointReached) {
                        Serial.print(x);
                        Serial.print(" ");
                        Serial.print(y);
                        Serial.println(" point reached");

                        currentPoint++;
                        if (currentPoint == POINTS_SIZE) {
                            currentPoint = 0;
                            awaitButton = true;
                            workState = GOING_TO_ZERO;
                            lastDirectionsDetected = false;
                            Serial.println("End of POINTS array");
                            Serial.println("Going to zero");
                        }

                        // если включен режим движения по нажатию кнопки, то сбрасываем флаг ожидания
                        if (NEXT_POINT_FROM_BUTTON) {
                            awaitButton = true;
                        }
                        if (CORRECTION_ENABLED) {
                            updateLastDirections();
                            correctedValues = false;
                        }
                    }
                }
            }
        } else if (workState == HEAD_MOVING) {
            bool headMoved = false;

            if (headPosition == DOWN) {
                headMoved = moveHead(0);
            } else if (headPosition == UP) {
                headMoved = moveHead(1);
            }

            if (headMoved) {
                workState = AWAIT_COMMAND;
            }
        }
    }

}

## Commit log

2021-09-07 Add head moving (Z axis), fix power bug, add comments..
    [kinematics.ino]
2021-09-12 Fixes, refactoring... Work with pencil is ok
    [kinematics.ino]
2021-09-14 Add stop on button2, optimization..
2021-09-15 Add first variant of circe array generation (wrong)
    [kinematics.ino]
2021-09-17 Add comment about bug
    [kinematics.ino]
2021-09-18 Attempt to fix bug in goToPoint (draw triangle)
    [kinematics.ino]
2021-09-18 Fix bug! Add steppers speed correction
    [kinematics.ino]
2021-09-21 Add 3d models
    [base.SLDPRT, corner_rail_1.SLDPRT, corner_rail_2.SLDPRT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]
2021-09-21 Add some parts in 3d models, fix, rename..
    [general_assembly.SLDASM, stepper_rail_support_roller.SLDPRT, stepper_shaft_roller.SLDPRT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]
2021-09-21 Add new parts in 3d models, fix assembly..
    [base.SLDPRT, corner_rail_1.SLDPRT, corner_rail_2.SLDPRT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]
2021-09-22 Update readme, models
    [pencil.SLDPRT, pencil_2.SLDPRT]
2021-09-23 Fix parts, add general model screen in readme
    [general_assembly.SLDASM, table_1_stepper_rail_support.SLDPRT, table_stepper_rail_support.SLDPRT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]
2021-09-23 Add z_axis_rack_bracing model
    [corner_rail_1.SLDPRT, general_assembly.SLDASM, z_axis_rack_bracing_1_1.SLDPRT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]
2021-09-24 Add table supports in models..
    [corner_rail_1.SLDPRT, general_assembly.SLDASM, table_1.SLDPRT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]
2021-09-27 Update 3d models
    [general_assembly.SLDASM, table_1_stepper_holder.SLDPRT, table_2.SLDPRT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]
2021-09-27 Update general assembly screen
    [general_assembly.SLDASM]
2021-09-29 Update 3d models, add spring
    [general_assembly.SLDASM, pencil_bracing_spring.SLDPRT, z_axis_assembly_version_3_final.SLDASM]
2021-10-02 Add z axis assembly screen
    [z_axis_assembly_version_1.SLDASM]
